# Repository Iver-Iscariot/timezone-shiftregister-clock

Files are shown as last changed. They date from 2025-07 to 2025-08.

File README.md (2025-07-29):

# Timezone clock
Expandable, dynamic system for showing the time in different timezones.


Originally designed for use in Omega Verksted, as several members exchanged to different timezones.

The modules are chained together with one MCU at the end. The timezone for each module is set using the dip switch, and read to the MCU by shift registers. The corresponding numbers for 7-seg displays are then sent out on further registers. The dip-switch also instructs weather its the last in the chain, and if its supposed to show the minutes or the hours of the zone. The clock is design to be installed in two rows, one for hours and one for minutes

## Time zone DIP switch table
coming

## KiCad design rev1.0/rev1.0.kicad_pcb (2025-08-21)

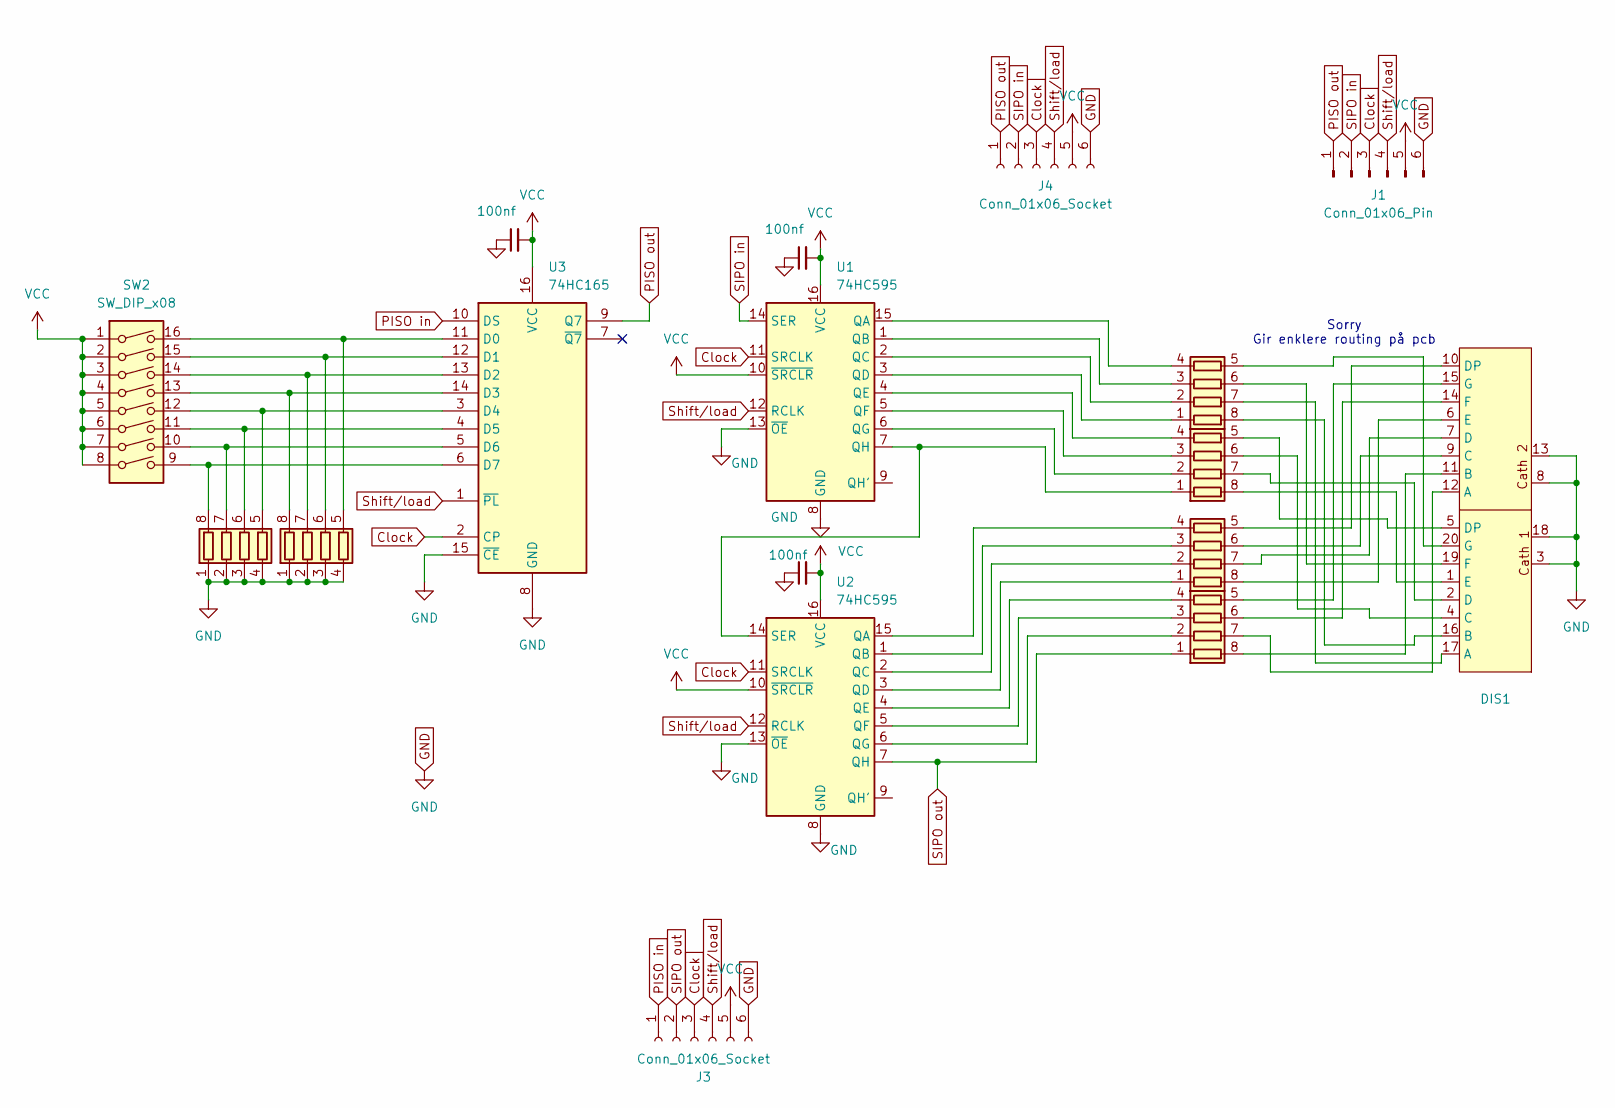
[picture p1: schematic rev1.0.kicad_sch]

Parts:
C1, C2, C3: 100nf; C_0603_1608Metric
DIS1: double digit 7 seg
J1: Conn_01x06_Pin; PinHeader_1x06_P2.54mm_Horizontal
J3, J4: Conn_01x06_Socket; flatcable conn 6
RN1, RN2, RN3, RN4, RN5, RN6: R_Pack04; R_Array_Concave_4x0603
SW2: SW_DIP_x08; SOIC-16_3.9x9.9mm_P1.27mm
U1, U2: 74HC595; SOIC-16_3.9x9.9mm_P1.27mm
U3: 74HC165; SOIC-16_3.9x9.9mm_P1.27mm

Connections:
Clock: J1.3, J3.3, J4.3, U1.11 (SRCLK), U2.11 (SRCLK), U3.2 (CP)
GND: C1.1, C2.1, C3.1, DIS1.3, DIS1.8, DIS1.13, DIS1.18, J1.6, J3.6, J4.6, RN1.1 (R1.1), RN1.2 (R2.1), RN1.3 (R3.1), RN1.4 (R4.1), RN2.1 (R1.1), RN2.2 (R2.1), RN2.3 (R3.1), RN2.4 (R4.1), U1.8 (GND), U1.13 (~OE), U2.8 (GND), U2.13 (~OE), U3.8 (GND), U3.15 (~CE)
unnamed: RN1.8 (R1.2), SW2.9, U3.6 (D7)
unnamed: RN1.7 (R2.2), SW2.10, U3.5 (D6)
unnamed: RN1.6 (R3.2), SW2.11, U3.4 (D5)
unnamed: RN1.5 (R4.2), SW2.12, U3.3 (D4)
unnamed: RN2.8 (R1.2), SW2.13, U3.14 (D3)
unnamed: RN2.7 (R2.2), SW2.14, U3.13 (D2)
unnamed: RN2.6 (R3.2), SW2.15, U3.12 (D1)
unnamed: RN2.5 (R4.2), SW2.16, U3.11 (D0)
unnamed: RN3.1 (R1.1), U1.3 (QD)
unnamed: DIS1.16 (B), RN3.8 (R1.2)
unnamed: RN3.2 (R2.1), U1.2 (QC)
unnamed: DIS1.17 (A), RN3.7 (R2.2)
unnamed: RN3.3 (R3.1), U1.1 (QB)
unnamed: DIS1.19 (F), RN3.6 (R3.2)
unnamed: RN3.4 (R4.1), U1.15 (QA)
unnamed: DIS1.20 (G), RN3.5 (R4.2)
unnamed: DIS1.11 (B), RN4.8 (R1.2)
unnamed: RN4.2 (R2.1), U2.6 (QG)
unnamed: DIS1.12 (A), RN4.7 (R2.2)
unnamed: RN4.3 (R3.1), U2.5 (QF)
unnamed: DIS1.14 (F), RN4.6 (R3.2)
unnamed: RN4.4 (R4.1), U2.4 (QE)
unnamed: DIS1.15 (G), RN4.5 (R4.2)
unnamed: RN5.1 (R1.1), U2.3 (QD)
unnamed: DIS1.6 (E), RN5.8 (R1.2)
unnamed: RN5.2 (R2.1), U2.2 (QC)
unnamed: DIS1.7 (D), RN5.7 (R2.2)
unnamed: RN5.3 (R3.1), U2.1 (QB)
unnamed: DIS1.9 (C), RN5.6 (R3.2)
unnamed: RN5.4 (R4.1), U2.15 (QA)
unnamed: DIS1.10 (DP), RN5.5 (R4.2)
unnamed: RN6.1 (R1.1), U1.7 (QH), U2.14 (SER)
unnamed: DIS1.1 (E), RN6.8 (R1.2)
unnamed: RN6.2 (R2.1), U1.6 (QG)
unnamed: DIS1.2 (D), RN6.7 (R2.2)
unnamed: RN6.3 (R3.1), U1.5 (QF)
unnamed: DIS1.4 (C), RN6.6 (R3.2)
unnamed: RN6.4 (R4.1), U1.4 (QE)
unnamed: DIS1.5 (DP), RN6.5 (R4.2)
PISO in: J3.1, U3.10 (DS)
PISO out: J1.1, J4.1, U3.9 (Q7)
SIPO in: J1.2, J4.2, U1.14 (SER)
SIPO out: J3.2, RN4.1 (R1.1), U2.7 (QH)
Shift/load: J1.4, J3.4, J4.4, U1.12 (RCLK), U2.12 (RCLK), U3.1 (~PL)
VCC: C1.2, C2.2, C3.2, J1.5, J3.5, J4.5, SW2.1, SW2.2, SW2.3, SW2.4, SW2.5, SW2.6, SW2.7, SW2.8, U1.10 (~SRCLR), U1.16 (VCC), U2.10 (~SRCLR), U2.16 (VCC), U3.16 (VCC)

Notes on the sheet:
Sorry Gir enklere routing på pcb

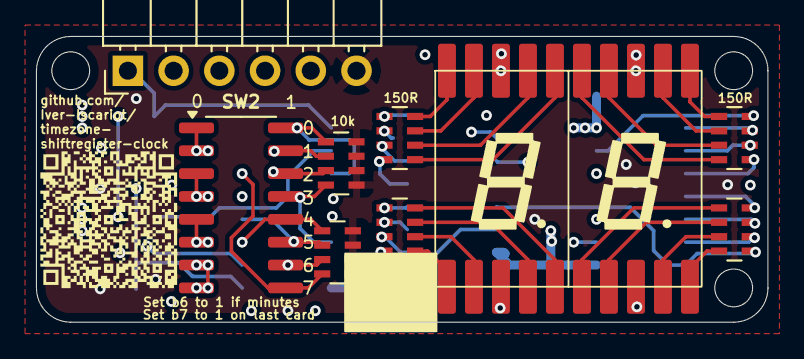
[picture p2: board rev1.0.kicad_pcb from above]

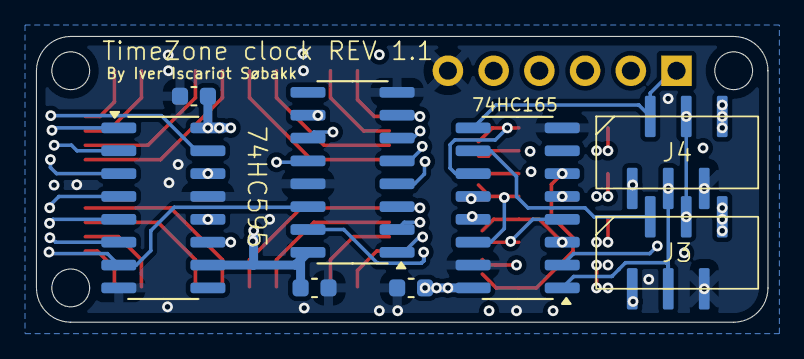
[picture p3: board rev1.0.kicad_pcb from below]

Board: 4 copper layers, 40.6 x 15.9 mm, 17 parts (8 on the bottom side), 47 nets.

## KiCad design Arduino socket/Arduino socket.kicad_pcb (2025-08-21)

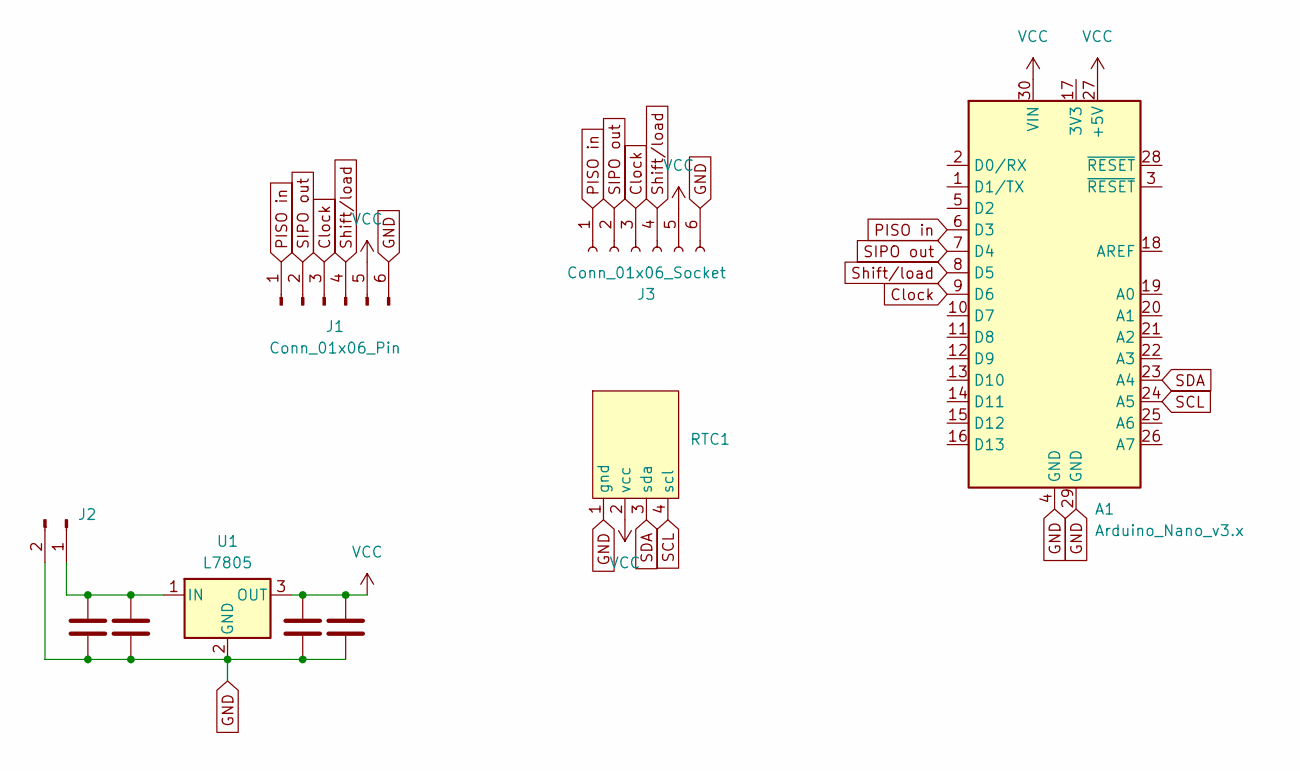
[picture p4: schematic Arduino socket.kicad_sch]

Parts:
A1: Arduino_Nano_v3.x; Arduino_Nano
C1, C2, C3, C4: C; C_0805_2012Metric_Pad1.18x1.45mm_HandSolder
J1: Conn_01x06_Pin; PinHeader_1x06_P2.54mm_Horizontal
J2: Conn_01x02_Pin; PinHeader_1x02_P2.54mm_Vertical
J3: Conn_01x06_Socket; flatcable conn 6
RTC1: DS3231 RTC module
U1: L7805; TO-220-3_Horizontal_TabDown

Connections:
Clock: A1.9 (D6), J1.3, J3.3
GND: A1.4 (GND), A1.29 (GND), C1.2, C2.2, C3.2, C4.2, J1.6, J2.2, J3.6, RTC1.1 (gnd), U1.2 (GND)
unnamed: C1.1, C2.1, J2.1, U1.1 (IN)
PISO in: A1.6 (D3), J1.1, J3.1
SCL: A1.24 (A5), RTC1.4 (scl)
SDA: A1.23 (A4), RTC1.3 (sda)
SIPO out: A1.7 (D4), J1.2, J3.2
Shift/load: A1.8 (D5), J1.4, J3.4
VCC: A1.27 (+5V), A1.30 (VIN), C3.1, C4.1, J1.5, J3.5, RTC1.2 (vcc), U1.3 (OUT)

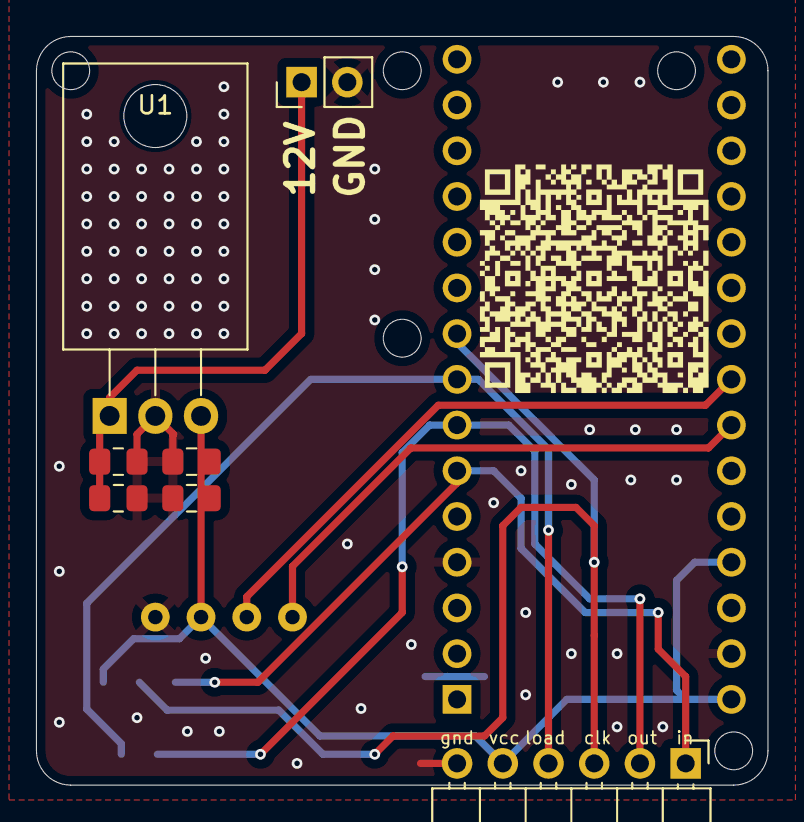
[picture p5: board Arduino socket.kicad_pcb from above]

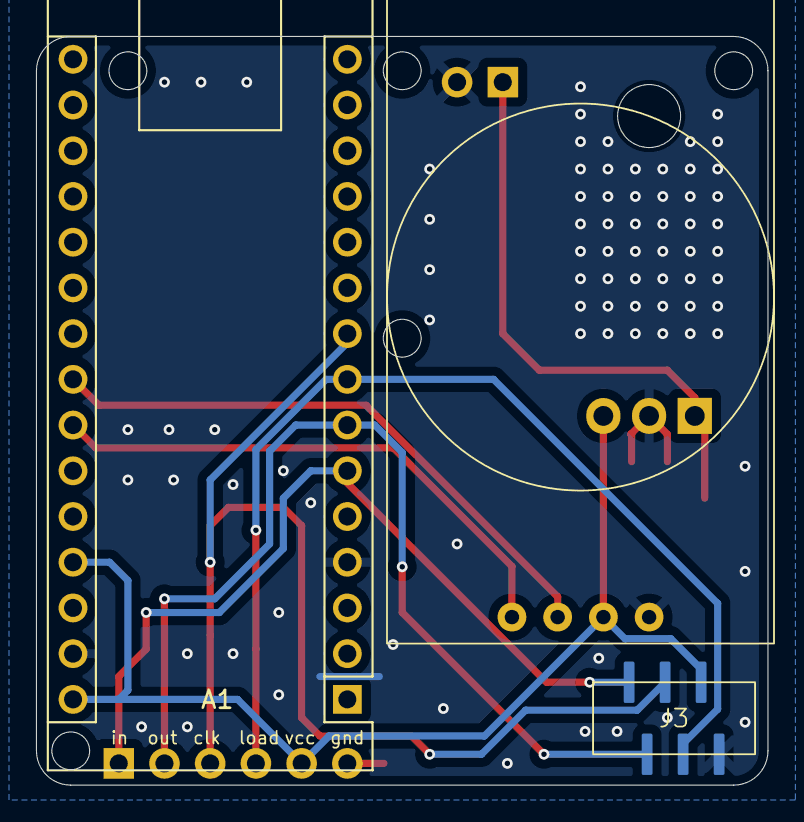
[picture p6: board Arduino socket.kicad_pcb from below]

Board: 2 copper layers, 40.6 x 41.6 mm, 10 parts (2 on the bottom side), 9 nets.

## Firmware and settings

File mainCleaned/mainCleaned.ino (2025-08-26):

#include <DS3231.h>
#include <Wire.h>



//####################################### time stuff ###############################
//borrowed from Eric Ayars 3231 library

DS3231 myRTC;

byte year;
byte month;
byte date;
byte dOW;
byte hour;
byte minute;
byte second;

void getDateStuff(byte& year, byte& month, byte& date, byte& dOW,
                  byte& hour, byte& minute, byte& second) {
    // Call this if you notice something coming in on
    // the serial port. The stuff coming in should be in
    // the order YYMMDDwHHMMSS, with an 'x' at the end.
    boolean gotString = false;
    char inChar;
    byte temp1, temp2;
    char inString[20];
    
    byte j=0;
    while (!gotString) {
        if (Serial.available()) {
            inChar = Serial.read();
            inString[j] = inChar;
            j += 1;
            if (inChar == 'x') {
                gotString = true;
            }
        }
    }
    Serial.println(inString);
    // Read year first
    temp1 = (byte)inString[0] -48;
    temp2 = (byte)inString[1] -48;
    year = temp1*10 + temp2;
    // now month
    temp1 = (byte)inString[2] -48;
    temp2 = (byte)inString[3] -48;
    month = temp1*10 + temp2;
    // now date
    temp1 = (byte)inString[4] -48;
    temp2 = (byte)inString[5] -48;
    date = temp1*10 + temp2;
    // now Day of Week
    dOW = (byte)inString[6] - 48;
    // now hour
    temp1 = (byte)inString[7] -48;
    temp2 = (byte)inString[8] -48;
    hour = temp1*10 + temp2;
    // now minute
    temp1 = (byte)inString[9] -48;
    temp2 = (byte)inString[10] -48;
    minute = temp1*10 + temp2;
    // now second
    temp1 = (byte)inString[11] -48;
    temp2 = (byte)inString[12] -48;
    second = temp1*10 + temp2;
}
//###########################################################################################


//####################################  Pins ################################################
const uint8_t PISO_DATA = 3; // 74HC165 Q7 -> D3
const uint8_t SIPO_DATA = 4; // 74HC595 DS -> D4
const uint8_t LATCH_PIN = 5; // 74HC165 SH/LD + 74HC595 RCLK -> D5
const uint8_t CLOCK_PIN = 6; // CLK shared -> D6
//###########################################################################################


//################################### module count ##########################################
// Upper bound for possible amount of connected modules (for safety) expand if nececarry
const uint8_t MAX_165 = 16;           
const uint8_t MAX_595 = MAX_165 * 2;
// the read bytes, and the bytes to be printed out
uint8_t inputBytes[MAX_165];   // holds one byte per 165
uint8_t outputBytes[MAX_595];  // holds one byte per 595
//###########################################################################################




// shortening for common on/off pulses
inline void pulseClock() { // pulse the clock once
  digitalWrite(CLOCK_PIN, HIGH);
  digitalWrite(CLOCK_PIN, LOW);
}




//######################################  data in/ 165 stuff  #########################################################

inline void load165() {   // load the paralell inputs for 165
  digitalWrite(LATCH_PIN, LOW);   // SH/LD low = load parallel
  delayMicroseconds(1);
  digitalWrite(LATCH_PIN, HIGH);  // back to shift mode
  delayMicroseconds(1);
}

// Reads one full 165 and tells you if it's the last one (only the last in the chain has b7 set to 1)
uint8_t read165Byte(bool &isLast) {
  uint8_t b = 0;
  int lastBit = 0;

  for (uint8_t i = 0; i < 8; i++) {
    int bitVal = digitalRead(PISO_DATA);
    b |= (bitVal << i);   
    pulseClock();
  }

  isLast = (b & 1) == 1;
  return b;
}


// read all of the 165's untill the one with a high b7 (sentinel)
void fillInput() {

  load165();

  // Read chip-by-chip until sentinel
  uint8_t num165 = 0;  // the number of 165's seen/modules connected
  for (; num165 < MAX_165; num165++) {
    bool lastChip = false;
    inputBytes[num165] = read165Byte(lastChip);
    if (lastChip) {
      num165++;  // count this one too
      break;
    }
  }
  //if (num165 == 0) return; // nothing detected


  // Debug print
  Serial.print("Read "); Serial.print(num165); Serial.println(" x 165's:");
  for (uint8_t i = 0; i < num165; i++) {
    Serial.print("Chip ");
    Serial.print(i);
    Serial.print(" = ");
    for (int bit = 7; bit >= 0; bit--) {
      Serial.print((inputBytes[i] >> bit) & 1);
    }
    Serial.println();
  }
}
//############################################################################################


//######################################  data out / 595 stuff  ##############################
void shift16bit(uint16_t word) {  // i thought you could pull latch low, shift all the bits through, then pull latch high to reveal it, but appearantly not. maybe i implemented something wrong in circuit, but if you do the latch outside the loop everything breaks
  for (int b = 15; b >= 0; b--) {    
    digitalWrite(LATCH_PIN, LOW);
    digitalWrite(SIPO_DATA, (word >> b) & 1);
    //delay(10);  // add back for cool shift register look
    pulseClock();
    digitalWrite(LATCH_PIN, HIGH);
  }
}


const uint8_t intTo8bitA[10] = {  // order of bits to represent a digit on the first of the displays
  0b01110111, // 0
  0b00010100, // 1
  0b10110011, // 2
  0b10110110, // 3
  0b11010100, // 4
  0b11100110, // 5
  0b11100111, // 6
  0b00110100, // 7
  0b11110111, // 8
  0b11110110 // 9
};
const uint8_t intTo8bitB[10] = {  // order of bits on second display. Ideally, this would have been the same, but that would have made routing a lot messier (blame whoever decided the 7seg pinout)
  0b01110111, // 0
  0b01000001, // 1
  0b00111011, // 2
  0b01101011, // 3
  0b01001101, // 4
  0b01101110, // 5
  0b01111110, // 6
  0b01000011, // 7
  0b01111111, // 8
  0b01101111 // 9
};

void shiftDigit(int num){  // the function that will be called in the main bit of the code. Get an int, figure out the corresponding word for each 7seg, and shift it all out
  uint8_t wordA;  uint8_t wordB;
  if(num > 9){
    wordA = intTo8bitA[num / 10];  // tieren i første digit
    wordB = intTo8bitB[num % 10];  // eneren i andre digit
  }
  else{
    wordA = intTo8bitA[0];         // 0 i første digit når vi er under 10
    wordB = intTo8bitB[num % 10];  // eneren i andre digit
  }

  uint16_t combined = ((uint16_t)wordA << 8) | wordB;  // concatenate 'em

  shift16bit(combined);
}
//############################################################################################



//############################# define module class, ohhh yeah baby, classes ############################################
class Module {      
  public:         
    float timezone;   // +- hours (including decimal)
    bool isMinute;    // is this a minute module ?
};


void setup() {
  // For RTC
  Wire.begin();

  // declare pinmodes
  pinMode(PISO_DATA, INPUT);
  pinMode(SIPO_DATA, OUTPUT);
  pinMode(LATCH_PIN, OUTPUT);
  pinMode(CLOCK_PIN, OUTPUT);

  // set initial values
  digitalWrite(CLOCK_PIN, LOW);
  digitalWrite(LATCH_PIN, HIGH);

  // todo: maybe increase for more accurate time-setting.
  Serial.begin(9600);

  fillInput(); // read the input registers
}

void loop() {
  // If something is coming in on the serial line, it's
    // a time correction so set the clock accordingly.
    if (Serial.available()) {
        getDateStuff(year, month, date, dOW, hour, minute, second);
        
        myRTC.setClockMode(false);  // set to 24h
        //setClockMode(true); // set to 12h
        
        myRTC.setYear(year);
        myRTC.setMonth(month);
        myRTC.setDate(date);
        myRTC.setDoW(dOW);
        myRTC.setHour(hour);
        myRTC.setMinute(minute);
        myRTC.setSecond(second);
        
        // Test of alarm functions
        // set A1 to one minute past the time we just set the clock
        // on current day of week.
        myRTC.setA1Time(dOW, hour, minute+1, second, 0x0, true,
                        false, false);
        // set A2 to two minutes past, on current day of month.
        myRTC.setA2Time(date, hour, minute+2, 0x0, false, false,
                        false);
        // Turn on both alarms, with external interrupt
        myRTC.turnOnAlarm(1);
        myRTC.turnOnAlarm(2);
        
    }


  // todo: implement the RTC, and figure out how it handles timezones, (need to know that before we go to the module-timezone controll)
  // todo: create "module" class, 
    // self variables:
        // timezone, 
        // weather it is a minute type
    // functions:
        // return time in self.timezone / return minute in self.timezone (if minute)
  
  delay(1000);      

  for(int i = 0; i <= 99; i++){  
    shiftDigit(i);
    delay(500);
  }
  
  delay(3000);
}

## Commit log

2025-06-17 Started work on circuit
    [rev1.0.kicad_pcb, rev1.0.kicad_sch]
2025-06-18 More wokr. Må bare koble sammen headers og registere
    [rev1.0.kicad_pcb, rev1.0.kicad_sch]
2025-06-18 Added last connections in schematic. just missing routing
2025-06-18 oop, forgot the PCB changes
    [rev1.0.kicad_pcb, rev1.0.kicad_sch]
2025-06-20 Gikk over til 4-lags for å få det mye mindre.
    Byttet også over til en full 8pin DIP-swith, og mindre pakke en jeg hadde først
    [rev1.0.kicad_pcb, rev1.0.kicad_sch]
2025-06-21 Completed pcb for module, and started an arduino socket w/ interconnect
    [Arduino socket.kicad_pcb, Arduino socket.kicad_sch, rev1.0.kicad_pcb]
2025-08-21 Started coding.
    Reading and writing to registers implemented.
    The circuit is now on rev 1.1, but there were some mistakes on this one to, hehe.
    The dip-switch is NOT the same size as a 16p soic, a little wider (bodgedd by bending pins under on one side (the one thats just all vcc anyways, as it can be bridged if you're struggeling with the jank solder)).
    The socket also has some mechanical solder points on the ends, that wasnt on my footprint. They are also thinner and longer than thought. The mechanical solder on one side could short some pins on the 165, but i simply put a piece of kapton tape acrross the pins. Circuit works otherwise. Perhaps a little hot. Maybe not ideal to drive LEDs di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
    [Arduino socket-B_Cu.gbr, Arduino socket-B_Mask.gbr, Arduino socket-B_Paste.gbr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]
